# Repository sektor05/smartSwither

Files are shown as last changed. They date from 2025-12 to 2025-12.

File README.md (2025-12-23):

# Smart CAN Bus Switcher

This project is a DIY home automation solution for smart lighting, built around a custom PCB that fits into a standard electrical switch box. It uses a wired CAN bus for robust communication, controlled by a central single-board computer like Orange Pi. This approach provides industrial-grade reliability for your smart home.

## Key Features

*   **Dual Load Control:** Each module has two on-board triacs, allowing it to control two independent lighting groups.
*   **Dimming Functionality:** Supports dimmable LED lamps for smooth brightness adjustments, enabling "sunrise" or "soft evening light" scenes.
*   **Built-in Climate Monitoring:** An integrated temperature sensor in every switch turns your entire home into a climate monitoring network.
*   **Reliable Communication:** Operates over a 2-pair cable, with one pair for 12/24V power and the other for the CAN differential line.

## System Architecture

The heart of the system is a single-board computer (e.g., Orange Pi), which acts as the central brain.

1.  **Central Controller (Orange Pi):**
    *   Collects data from all switches via the CAN bus.
    *   Processes all automation logic (e.g., an "All Off" button at the entrance).
    *   Integrates with external services and voice assistants like Yandex Alice.
2.  **Smart Switch Modules:** Custom PCBs installed in wall switch boxes. They execute commands received from the controller and report status and sensor data.
3.  **CAN Bus:** The backbone of the system, providing a high-speed, reliable, and noise-immune communication link between the controller and all modules.

The server software can be implemented using platforms like **Home Assistant** or custom applications written in **Python/C++**, allowing for easy integration with smart home ecosystems. A command like *"Alice, set the living room light to 30%"* is sent to the Orange Pi, which instantly relays it to the appropriate module on the CAN bus to adjust the light level.

## Why CAN Bus over Zigbee/Wi-Fi?

For a new construction or major renovation, a wired solution offers significant advantages over popular wireless protocols.

| Characteristic | This Solution (CAN Bus) | Popular Wireless (Zigbee) |
| --- | --- | --- |
| **Reliability** | Maximum. Immune to interference from Wi-Fi or microwaves. | Depends on RF signal quality and the number of repeaters. |
| **Speed** | Instantaneous response (milliseconds). | Delays are possible as nodes wake up or the mesh network adjusts. |
| **Power** | Centralized. No batteries to replace in sensors. | Requires battery changes or modules connected to a neutral wire. |
| **Scalability** | Line length can extend to hundreds of meters. | Limited by the radio signal range. |

The main benefit: a wired system is a "set it and forget it" solution. It won't fail because of a router firmware update or a new neighbor's Wi-Fi network.

## Project Structure

*   **/firmware/**: Contains firmware for the microcontroller (STM32/Arduino) on the switch modules. Includes projects for PlatformIO and STM32Cube.
*   **/hardware/**: Datasheets for components used in the project.
*   **/production/**: PCB manufacturing files, including KiCad project, Gerber files, and Bill of Materials (BOM).
*   **/software/**: Server-side applications and scripts for the Orange Pi.
*   **/documents/**: Design documents, manuals, and reports.

## Installation and Wiring

The system uses a 2-pair cable (e.g., KSPV or shielded twisted pair) for both power and data.

*   **Pair 1:** Power (GND / VCC)
*   **Pair 2:** Data (CAN-High / CAN-Low)

The PCB is designed to be compact, leaving enough space for wiring even in shallow switch boxes.

## Related Articles

*   [Умный свет своими руками: Делаем "умным" любой выключатель по шине CAN](https://project-wave.ru/2025/12/23/%d1%83%d0%bc%d0%bd%d1%8b%d0%b9-%d1%81%d0%b2%d0%b5%d0%b4-%d1%81%d0%b2%d0%be%d0%b8%d0%bc%d0%b8-%d1%80%d1%83%d0%ba%d0%b0%d0%bc%d0%b8-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)

The next article will provide a detailed breakdown of the PCB schematic, component selection, and the board layout process in EasyEDA/KiCad.

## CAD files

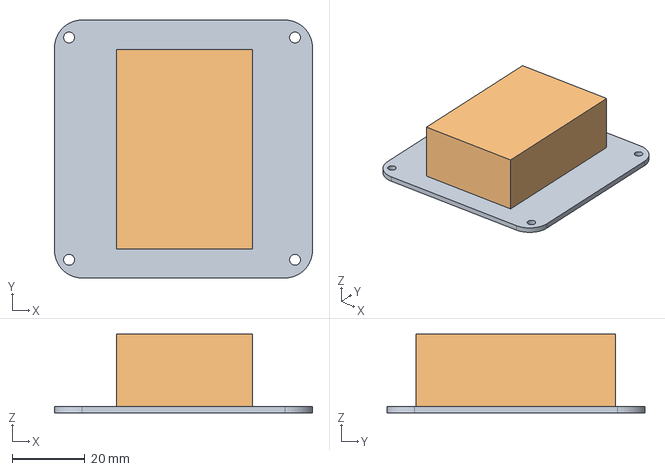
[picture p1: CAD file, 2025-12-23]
production/включаетль.FCStd
70.8 x 70.8 x 21.6 mm
Куб001

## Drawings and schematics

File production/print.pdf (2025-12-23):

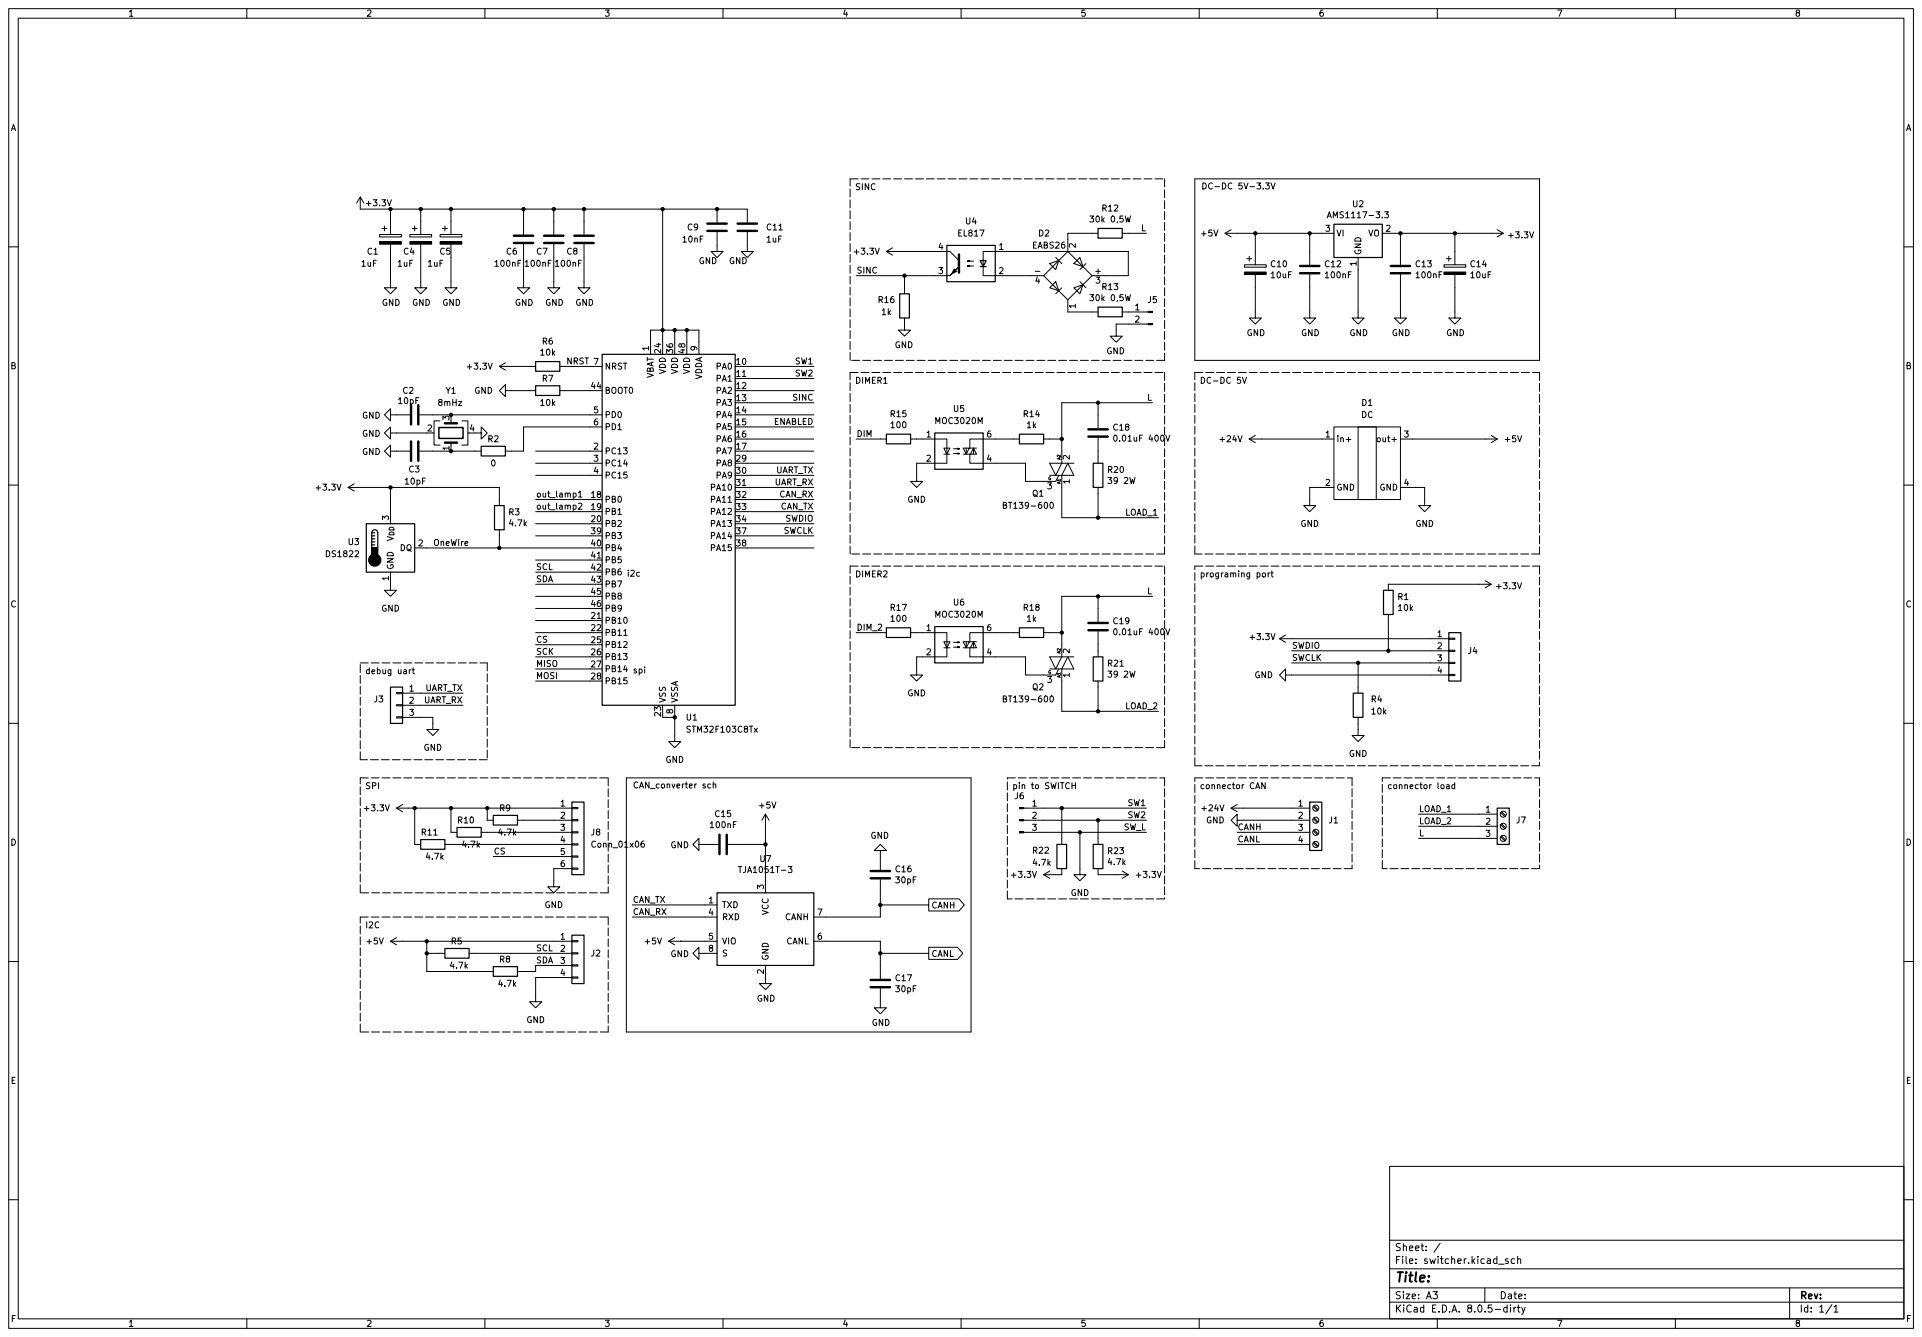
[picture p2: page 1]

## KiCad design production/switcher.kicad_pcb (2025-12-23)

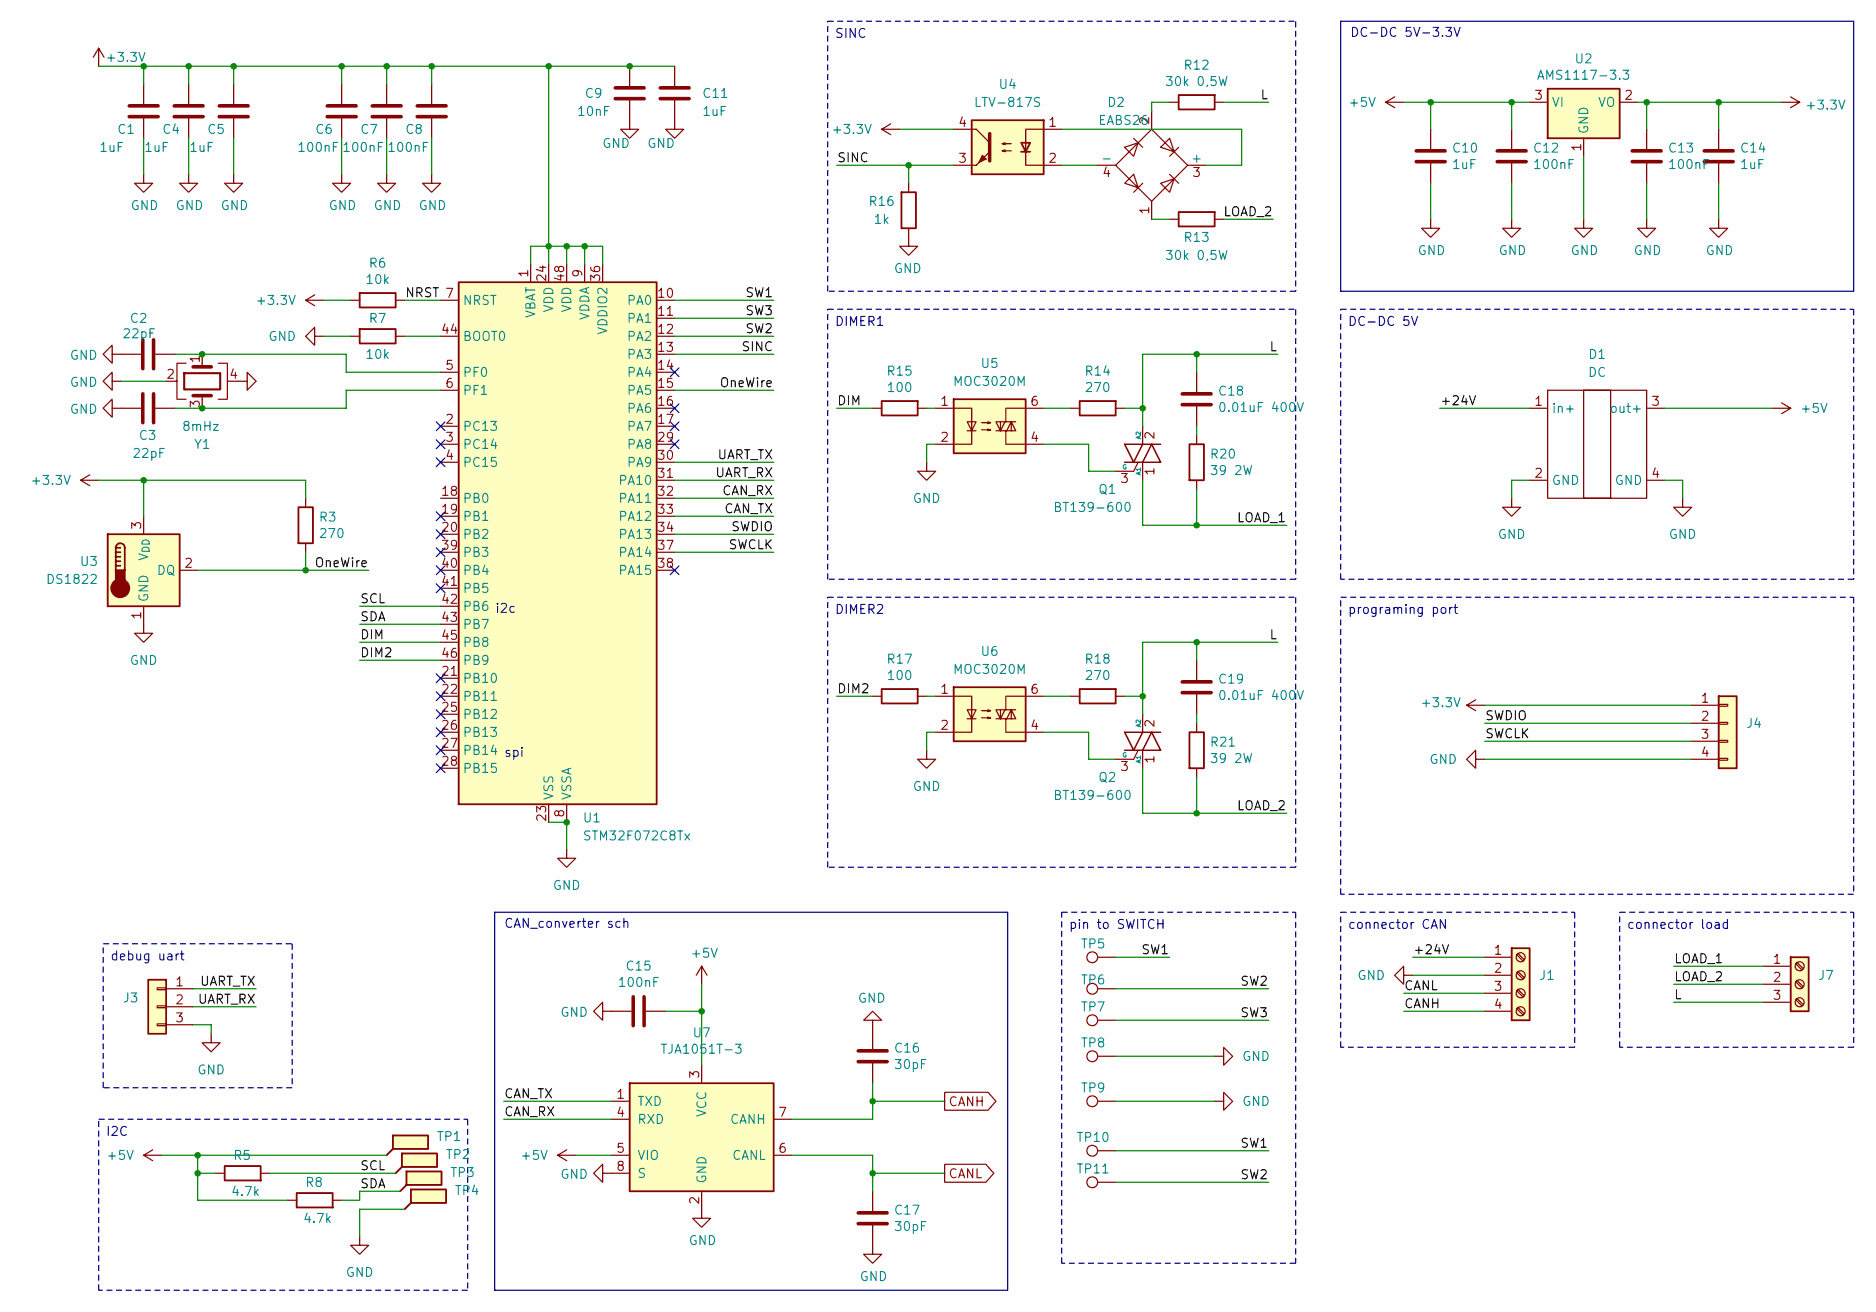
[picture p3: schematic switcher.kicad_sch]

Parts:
C1, C4, C5, C10, C11, C14: 1uF; C_0805_2012Metric
C2, C3: 22pF; C_0805_2012Metric
C6, C7, C8, C12, C13, C15: 100nF; C_0805_2012Metric
C9: 10nF; C_0805_2012Metric
C16, C17: 30pF; C_0805_2012Metric
C18, C19: 0.01uF 400V; C_Rect_L10.0mm_W2.5mm_P7.50mm_MKS4
D1: DC; 30V 3A
D2: EABS26; Diode_Bridge_Diotec_ABS
J1: Screw_Terminal_01x04; KF128-4P
J3: Conn_01x03
J4: Conn_01x04; PinHeader_1x04_P2.54mm_Vertical
J7: Screw_Terminal_01x03; KF128-3P
Q1, Q2: BT139-600; TO-220-3_Vertical
R3: 270; R_0805_2012Metric
R5, R8: 4.7k; R_0805_2012Metric
R6, R7: 10k; R_0805_2012Metric
R12, R13: 30k 0,5W; R_1206_3216Metric
R14, R18: 270; R_1206_3216Metric
R15, R17: 100; R_0805_2012Metric
R16: 1k; R_0805_2012Metric
R20, R21: 39 2W; R_Axial_DIN0414_L11.9mm_D4.5mm_P5.08mm_Vertical
TP1, TP2, TP3, TP4: TestPoint_Flag; TestPoint_Pad_1.0x1.0mm
TP5, TP6, TP7, TP8, TP9, TP10, TP11: TestPoint; TestPoint_Loop_D2.60mm_Drill1.6mm_Beaded
U1: STM32F072C8Tx; LQFP-48_7x7mm_P0.5mm
U2: AMS1117-3.3; SOT-223-3_TabPin2
U3: DS1822; TO-92_Inline
U4: LTV-817S; SMDIP-4_W9.53mm
U5, U6: MOC3020M; DIP-6_W7.62mm
U7: TJA1051T-3; SOIC-8_3.9x4.9mm_P1.27mm
Y1: 8mHz; Crystal_SMD_5032-4Pin_5.0x3.2mm

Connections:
+3.3V: C1.1, C4.1, C5.1, C6.1, C7.1, C8.1, C9.2, C11.1, C13.1, C14.1, J4.1, R3.1, R6.2, U1.1 (VBAT), U1.9 (VDDA), U1.24 (VDD), U1.36 (VDDIO2), U1.48 (VDD), U2.2 (VO), U3.3 (V_{DD}), U4.4
+5V: C10.1, C12.1, C15.1, D1.3 (out+), R5.1, R8.1, TP1.1, U2.3 (VI), U7.3 (VCC), U7.5 (VIO)
/+24V: D1.1 (in+), J1.1
/CAN_RX: U1.32 (PA11), U7.4 (RXD)
/CAN_TX: U1.33 (PA12), U7.1 (TXD)
/DIM: R15.1, U1.45 (PB8)
/DIM2: R17.1, U1.46 (PB9)
/L: C18.1, C19.1, J7.3, Q1.2 (A2), Q2.2 (A2), R12.2, R14.2, R18.2
/LOAD_1: J7.1, Q1.1 (A1), R20.2
/LOAD_2: J7.2, Q2.1 (A1), R13.2, R21.2
/NRST: R6.1, U1.7 (NRST)
/OneWire: R3.2, U1.15 (PA5), U3.2 (DQ)
/SCL: R5.2, TP2.1, U1.42 (PB6)
/SDA: R8.2, TP3.1, U1.43 (PB7)
/SINC: R16.2, U1.13 (PA3), U4.3
/SW1: TP5.1, TP10.1, U1.10 (PA0)
/SW2: TP6.1, TP11.1, U1.12 (PA2)
/SW3: TP7.1, U1.11 (PA1)
/SWCLK: J4.3, U1.37 (PA14)
/SWDIO: J4.2, U1.34 (PA13)
/UART_RX: J3.2, U1.31 (PA10)
/UART_TX: J3.1, U1.30 (PA9)
CANH: C16.2, J1.4, U7.7 (CANH)
CANL: C17.1, J1.3, U7.6 (CANL)
GND: C1.2, C2.1, C3.1, C4.2, C5.2, C6.2, C7.2, C8.2, C9.1, C10.2, C11.2, C12.2, C13.2, C14.2, C15.2, C16.1, C17.2, D1.2 (GND), D1.4 (GND), J1.2, J4.4, R7.2, R16.1, TP4.1, TP8.1, TP9.1, U1.8 (VSSA), U1.23 (VSS), U1.35 (VSS), U1.47 (VSS), U2.1 (GND), U3.1 (GND), U5.2, U6.2, U7.2 (GND), U7.8 (S), Y1.2, Y1.4
unnamed: C18.2, R20.1
unnamed: C19.2, R21.1
unnamed: D2.3 (+), U4.1
unnamed: D2.4 (-), U4.2
unnamed: D2.1, R13.1
unnamed: D2.2, R12.1
unnamed: Q1.3 (G), U5.4
unnamed: Q2.3 (G), U6.4
unnamed: R14.1, U5.6
unnamed: R15.2, U5.1
unnamed: R17.2, U6.1
unnamed: R18.1, U6.6
unnamed: R7.1, U1.44 (BOOT0)
unnamed: C2.2, U1.5 (PF0), Y1.1
unnamed: C3.2, U1.6 (PF1), Y1.3

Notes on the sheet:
spi
DC-DC 5V-3.3V
i2c
CAN_converter sch
DIMER1
programing port
DIMER2
pin to SWITCH
I2C
DC-DC 5V
SINC
connector CAN
connector load
debug uart

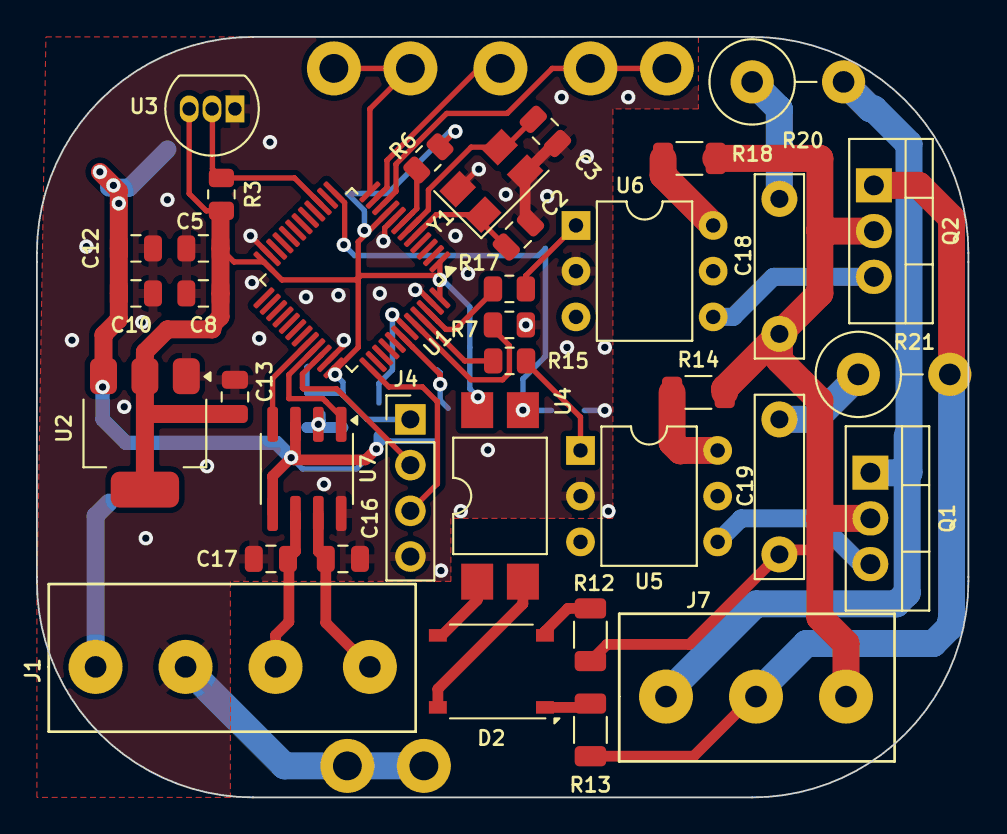
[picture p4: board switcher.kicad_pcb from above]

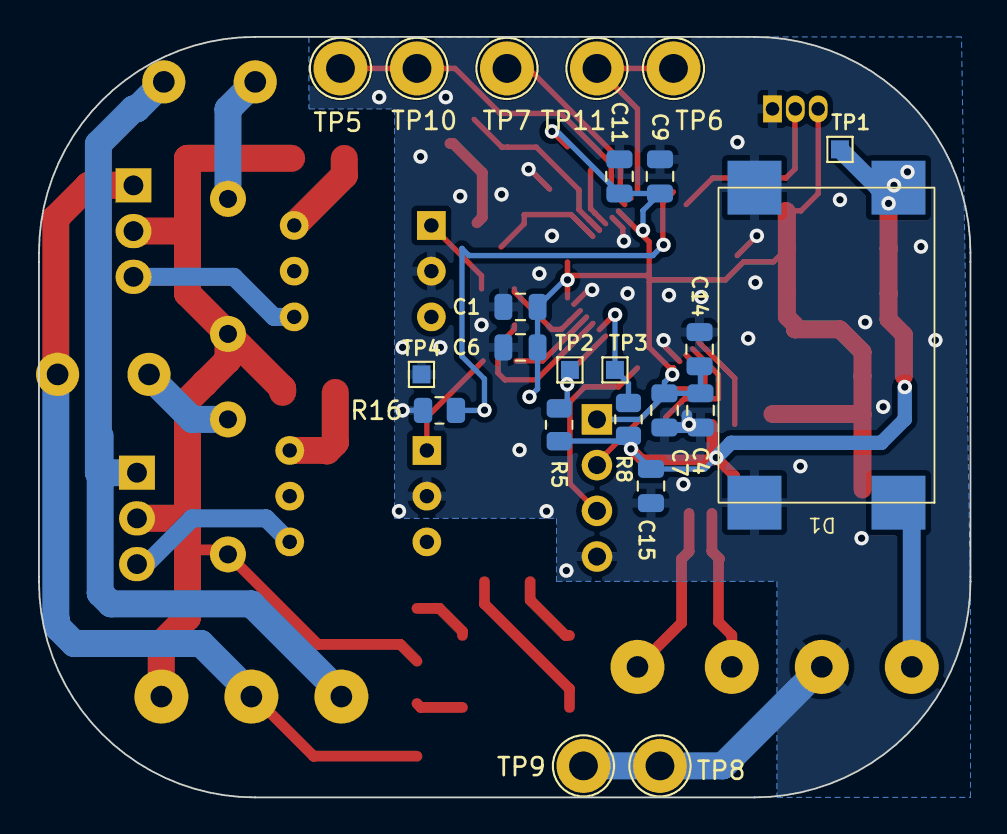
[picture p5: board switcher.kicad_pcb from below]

Board: 2 copper layers, 51.8 x 42.2 mm, 59 parts (23 on the bottom side), 38 nets.

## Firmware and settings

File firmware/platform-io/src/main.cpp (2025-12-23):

/*
 * Основной файл прошивки для умного переключателя на базе STM32F103
 * Реализует управление диммерами, обработку входов, CAN-коммуникацию и измерение температуры
 */

#include <Arduino.h>
#include "myBoard.h"
#include <Wire.h>
#include <cstdint>
#include <eXoCAN.h>
#include <iterator>
#include <stm32f1xx.h>
#include <stm32f1xx_hal.h>
#include <stm32f1xx_ll_gpio.h>
// Явные объявления функций memcpy, memset, memcmp для обхода проблем компиляции

// Создание экземпляра класса платы
myBoard board;

//------------------входные переменные--------------------------------
// Переменные для хранения предыдущих состояний входов
bool prevIn1, prevIn2, prevIn3, prevIn4;
// Переменные для хранения текущих состояний входов
bool in1, in2, in3, in4;

// Объявление аппаратных таймеров для различных задач
HardwareTimer timer(TIM2), timPWM(TIM1), timTemp(TIM3);

// Переменные для CAN-соединения
int id = 0, fltIdx = 0;

// Пины для управления диммерами
const uint16_t dimPins[] = {DIM_PIN, DIM2_PIN};
bool sendFlag = false;
// Буфер для отслеживания изменений в EEPROM (больше не нужен)
// uint8_t flagDataEEPROM[8];
//-----------------------------------------------------
// Буфер для приёма CAN-сообщений
uint8_t rxbytes[8];

int indexAdres = 0;
// Интервал отправки данных о температуре (30 секунд)
#define SEND_TEMP_TIME 30000 // sec

//---------------------------------счётчики------------------------------------------
uint32_t count = 0;
uint16_t tic = 0;

//----------------------------------температура--------------------------------------
#define maxSensors 1
// Массив для хранения значений температуры (в десятых долях градуса)
uint16_t temp[maxSensors];
bool flagD = false;

// Флаги для отслеживания изменений EEPROM (больше не нужны, т.к. запись идет в прерывании)
// bool eepromChanged = false;
// uint32_t lastEepromSave = 0;
// #define EEPROM_SAVE_DELAY 1000 // ms

///////////////////////////////объявления функций///////////////////////////////////////////////
void detect_down();
void detect_up();

/**
 * @brief Чтение температуры с датчика LM335
 * @return Температура в градусах Цельсия
 *
 * Функция считывает аналоговое значение с датчика LM335,
 * преобразует его в напряжение, а затем в температуру по формуле:
 * T(°C) = (V * 100) - 273.15
 */
double readTemperatureLM335() {
   // Считываем сырое значение с АЦП (12-бит, диапазон 0-4095)
   int raw = analogRead(ONE_W);
   // Преобразуем сырое значение в напряжение (опорное 3.3В)
   double voltage = raw * (3.3f / 4095.0f);
   // Преобразуем напряжение в температуру по формуле датчика LM335
   double temperatureC = (voltage * 100) - 273.15f;
   return temperatureC;
}

//------------------------обработчик прерывания CAN-------------------------------------
/**
 * @brief Обработчик прерывания для приёма CAN-сообщений
 *
 * Функция обрабатывает входящие CAN-сообщения различных типов:
 * - EEPROM: сохранение конфигурации
 * - OK: подтверждение получения
 * - PWM1/PWM2: управление ШИМ-каналами
 */
void canRecive() {
    // Проверяем наличие принятых данных
    uint8_t _data[1] = {1};
    if(board.receive(id, fltIdx, rxbytes) > 0) {
       
       // Обработка сообщения для записи в EEPROM
       if(id == (CAN_ID_EEPROM + board.addres)) {
          // Копируем данные в буфер
          memcpy(board.dataEPPROM, rxbytes, sizeof(board.dataEPPROM));
          // Прямая запись в EEPROM из прерывания
          board.saveDataToEPPROM(board.dataEPPROM);
          // Отправляем подтверждение приёма
          board.transmit(CAN_ID_OKtx, _data, sizeof(_data));
          // Перезагрузка микроконтроллера без задержки
          NVIC_SystemReset();
          
       } else if(id == (CAN_ID_OKrx + board.addres)) {
          // Обработка подтверждения получения
          if(_data[0]) board.canResponseFlag = true;
          
       } else if(id == (CAN_ID_PWM1 + board.addres)) {
          // Управление первым ШИМ-каналом
          // rxbytes[0] - целевое значение ШИМ (%)
          // rxbytes[1] - время перехода (мс)
          // rxbytes[2] - начальное значение ШИМ (%)
          board.PWM(0, rxbytes[0], rxbytes[1], rxbytes[2]);
          board.transmit(CAN_ID_OKtx + board.addres, _data, sizeof(_data));
          
       } else if(id == (CAN_ID_PWM2 + board.addres)) {
          // Управление вторым ШИМ-каналом
          board.PWM(1, rxbytes[0], rxbytes[1], rxbytes[2]);
          board.transmit(CAN_ID_OKtx + board.addres, _data, sizeof(_data));
       }
    }
}


//-----------обработчики прерываний по таймеру----------------
/**
 * @brief Обновление значений ШИМ
 *
 * Вызывается по прерыванию таймера для плавного изменения значений ШИМ
 */
void updatePWM() {
   board.updatePWM();
}

/**
 * @brief Отправка данных о температуре по CAN
 *
 * Вызывается по прерыванию таймера с периодом SEND_TEMP_TIME
 */
void sendTempCan() {
   double tempC = readTemperatureLM335();
   // Сохраняем температуру в десятых долях градуса для точности
   temp[0] = static_cast<int16_t>(tempC * 10);
   board.canTX16(CAN_ID_TEMP + board.addres, temp, 1); // 1 датчик, не 2
}

/**
 * @brief Прерывание для управления диммером (без нейтрали)
 *
 * Управляет моментом открытия симистора в зависимости от фазы переменного тока
 */
void isr() {
   tic++;

   for (int i = 0; i < 2; i++) {
      // Проверяем, находится ли значение диммера в допустимом диапазоне
      if ((board.dimmer[i] < MIN_DIM) && (board.dimmer[i] > MAX_DIM)) {
         // В нужный момент времени открываем симистор
         if (tic == board.dimmer[i]) {
            HAL_GPIO_WritePin(GPIOB, dimPins[i], GPIO_PIN_SET);
         } else if (tic >= board.dimmer[i] + 2) {
            // Закрываем симистор через 2 тика после открытия
            HAL_GPIO_WritePin(GPIOB, dimPins[i], GPIO_PIN_RESET);
            // Для второго канала останавливаем таймер
            if (i == 1) timer.pause();
         }
      } else {
         // Если значение вне диапазона, устанавиваем постоянное состояние
         GPIO_PinState st = (board.dimmer[i] == 0) ? GPIO_PIN_SET : GPIO_PIN_RESET;
         HAL_GPIO_WritePin(GPIOB, dimPins[i], st);
      }
   }
}

/**
 * @brief Обработчик перехода через ноль (detect_up)
 *
 * Сбрасывает счётчик и перезапускает таймер при обнаружении перехода через ноль
 */
void detect_up() {
   tic = 0;
   // Сбрасываем оба выхода диммера
   HAL_GPIO_WritePin(GPIOB, dimPins[1], GPIO_PIN_RESET);
   HAL_GPIO_WritePin(GPIOB, dimPins[0], GPIO_PIN_RESET);
   timer.setCount(0);
   timer.refresh();
   timer.resume();
}

/**
 * @brief Прерывание для CAN-шины
 */
void canISR() {
    canRecive();
}

/**
 * @brief Инициализация системы
 *
 * Настраивает все периферийные устройства: CAN, таймеры, прерывания
 */
void setup() {
   // Инициализация платы и CAN-интерфейса
   board.initBoard();
   board.attachInterrupt(canISR);
   
   //-----------------настройка прерываний-----------------------
   // Прерывание по переходу через ноль (детектор синхронизации)
   attachInterrupt(SINC, detect_up, RISING);
   
   // Настройка таймера для плавного изменения ШИМ
   // TODO: Исправить прерывания таймера для совместимости с текущей версией библиотеки
   // timPWM.setMode(1, TIMER_OUTPUT_COMPARE);
   // timPWM.setCompare(1, 0);
   timPWM.attachInterrupt(updatePWM);
   timPWM.setOverflow(MIN_DIM, HERTZ_FORMAT);
   timPWM.resume();

   // Настройка таймера для периодической отправки температуры
   // TODO: Исправить прерывания таймера для совместимости с текущей версией библиотеки
   // timTemp.setMode(1, TIMER_OUTPUT_COMPARE);
   // timTemp.setCompare(1, 0);
   timTemp.attachInterrupt(sendTempCan);
   timTemp.setOverflow(SEND_TEMP_TIME*1000, MICROSEC_FORMAT);
   timTemp.resume();
   
   // Настройка таймера для управления диммером (40 мкс период)
   // TODO: Исправить прерывания таймера для совместимости с текущей версией библиотеки
   // timer.setMode(1, TIMER_OUTPUT_COMPARE);
   // timer.setCompare(1, 0);
   timer.attachInterrupt(isr);
   timer.setOverflow(40, MICROSEC_FORMAT);
   
   // Инициализация значений диммеров (выключены)
   board.dimmer[0] = 255;
   board.dimmer[1] = 255;

   // Первоначальная отправка температуры при старте
   double tempC = readTemperatureLM335();
   temp[0] = static_cast<int16_t>(tempC * 10);
   board.canTX16(CAN_ID_TEMP + board.addres, temp, 1);
   
   // Буфер flagDataEEPROM больше не нужен, т.к. запись в EEPROM происходит в прерывании
}

uint32_t last = 0;

/**
 * @brief Основной цикл программы
 *
 * Обрабатывает входы, управляет ШИМ, обрабатывает CAN-сообщения
 * и сохраняет изменения в EEPROM при необходимости
 */
void loop() {
   //------------чтение и отправка состояний входов----------------------------
   board.controlIn();  // Считываем состояния входов
   board.processCan(); // Обрабатываем очередь CAN-сообщений
   // Отправляем состояния входов по CAN
   board.canTX(CAN_ID_IN + board.addres, board.in, sizeof(board.in));
   
   // Управление ШИМ на основе состояний входов (локальный режим)
   if(!board.serverAvail) {
      // Если хотя бы один вход активен (низкий уровень), включаем ШИМ
      if(!board.in[0] || !board.in[1] || !board.in[2]) {
         board.PWM(0, 100, 0, 0); // Включаем первый канал на 100%
         board.PWM(1, 100, 0, 0); // Включаем второй канал на 100%
      } else {
         board.PWM(0, 0, 0, 0);   // Выключаем первый канал
         board.PWM(1, 0, 0, 0);   // Выключаем второй канал
      }
   }

   // Сохранение в EEPROM теперь происходит напрямую в прерывании canRecive()
   // Этот код больше не нужен
   
   delay(10); // Небольшая задержка для стабильности работы
}

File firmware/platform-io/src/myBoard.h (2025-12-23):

/*
 * Заголовочный файл класса myBoard
 * Определяет функционал для управления платой умного переключателя
 * Включает управление диммерами, CAN-коммуникацию, работу с EEPROM
 */

#ifndef MY_BOARD_H
#define MY_BOARD_H

/*
 * Заголовочный файл класса myBoard
 * Определяет функционал для управления платой умного переключателя:
 * - Управление диммерами и ШИМ
 * - CAN-коммуникация
 * - Работа с EEPROM
 * - Обработка входов
 */

#include <Arduino.h>
#include "EEPROM.h"
#include <eXoCAN.h>
#include <stm32f1xx.h>
#include <cstring>
#include <stm32f1xx_hal.h>

// Явные объявления функций memcpy, memset, memcmp для обхода проблем компиляции
extern "C" {
void *memcpy(void *dest, const void *src, size_t n);
void *memset(void *s, int c, size_t n);
int memcmp(const void *s1, const void *s2, size_t n);
}
//------------------определения пинов-------------------

// Пины управления диммерами
#define DIM_PIN PB8
#define DIM2_PIN PB9

// Входные пины
#define IN_1 PA0
#define IN_2 PA1
#define IN_3 PA2

// Пин детектора перехода через ноль (синхронизация)
#define SINC PA3

// CAN-шина пины
#define CAN_RX PA11
#define CAN_TX PA12

// I2C пины
#define I2C_SCL PB6
#define I2C_SDA PB7

// Пины для датчиков
#define ONE_W PA5
#define TEMP_SENSOR_PIN PA5  // Пин, к которому подключён LM335Z

// Адрес в EEPROM для хранения конфигурации
#define CONFIG_ADDR 10

// Пределы диммера (значения для таймера)
#define MIN_DIM 200  // Минимальное значение (максимальная яркость)
#define MAX_DIM 0    // Максимальное значение (минимальная яркость)

//------------------параметры CAN-сообщений (приём)-----------------------
#define CAN_ID_GLOBAL 800  // Глобальный CAN ID
#define CAN_ID_PWM1 801    // Управление первым ШИМ-каналом
#define CAN_ID_PWM2 802    // Управление вторым ШИМ-каналом
#define CAN_ID_EEPROM 803  // Запись в EEPROM
#define CAN_ID_OKrx 804    // Подтверждение приёма

//-------параметры CAN-сообщений (передача)---------------------
#define CAN_ID_IN 806      // Состояния входов
#define CAN_ID_TEMP  807   // Датчик температуры
#define CAN_ID_OKtx 808    // Подтверждение передачи

//----------------индексы данных в EEPROM-----------------
#define CONFIG 0          // Конфигурация устройства


//---------------типы конфигурации устройства-----------------------
#define COSTOM 0          // Пользовательский режим
#define POWER 1           // Режим управления питанием
#define RESTROOM 2        // Режим для ванной комнаты
#define KICHEN 3          // Режим для кухни


/**
 * @brief Класс управления платой умного переключателя
 *
 * Наследуется от eXoCAN для обеспечения CAN-коммуникации.
 * Реализует управление диммерами, ШИМ, обработку входов и работу с EEPROM.
 */
class myBoard: public eXoCAN {
    public:
        // Публичные переменные
        uint8_t config=0;              // Тип конфигурации устройства
        uint8_t addres=0;              // Адрес устройства в CAN-сети
        uint8_t led2=0, led3=0, led4=0; // Состояния светодиодов
        
        uint8_t in[4];                 // Состояния входов
        uint8_t dataEPPROM[8];         // Данные из EEPROM
        uint8_t pwm_balast=0;          // Значение ШИМ балласта для первой лампы, когда включена вторая лампа. Необходима для детектора нуля.
        bool serverAvail = true;       // Флаг доступности сервера CAN

        // Публичные методы
        void initBoard();              // Инициализация платы
        bool contrCheng(int &previousData, int data); // Проверка изменения данных
       
        bool controlIn();              // Контроль входов
        uint8_t IN1();                 // Чтение состояния входа 1
        uint8_t IN2();                 // Чтение состояния входа 2
        uint8_t IN3();                 // Чтение состояния входа 3
        uint8_t dimmer[2];             // Значения диммеров
       
        
        uint8_t PWM(uint8_t chinal, uint8_t pwm, uint16_t time, uint8_t startPercent); // Управление ШИМ с плавным изменением
     
        void exponentialPWM(uint8_t pin, uint16_t duration); // Экспоненциальное изменение ШИМ
        void PWM(uint8_t pin, uint8_t percent);               // Простое управление ШИМ

        // CAN-методы
        bool canTX(int txId, uint8_t *ptr, uint8_t len, bool waitAck = true); // Отправка CAN-сообщения с ожиданием подтверждения
        bool canTX16(int txId, uint16_t *ptr, uint8_t len);                    // Отправка 16-битных данных по CAN
        bool canTX16_notAks(int txId, uint16_t *ptr, uint8_t len);            // Отправка 16-битных данных без подтверждения
        bool canTX_notCont(int txId, const void *ptr, uint8_t len);           // Отправка без непрерывного подтверждения
        void processCan(); // Обработка очереди CAN-сообщений (неблокирующая)
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

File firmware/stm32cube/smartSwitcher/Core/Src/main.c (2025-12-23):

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
/* Includes ------------------------------------------------------------------*/
#include "main.h"
#include "adc.h"
#include "can.h"
#include "dma.h"
#include "tim.h"
#include "gpio.h"

/* USER CODE BEGIN Includes */
#include "stm32f1xx_hal.h"
#include "stm32f1xx_ll_adc.h"
#include "flash_storage.h"
#include "string.h"
/* USER CODE END Includes */


/* USER CODE BEGIN PV */

uint16_t tic = 0;
const uint16_t dimPins[] = {DIM1_Pin, DIM2_Pin};
board_t Brd;
telemetry_t BrdTel;
dimmer_t dm[2] = {
    {MAX_DIM, 10, 10,MIN_DIM, MAX_DIM}, // Диммер 1
    {MAX_DIM, 10, 10,MIN_DIM, MAX_DIM}  // Диммер 2
};
/* USER CODE END PV */

void SystemClock_Config(void);
/* USER CODE BEGIN PFP */

//-------------прерывания по изменения яркости -----------------------
void LightControlDM1() {
    if (dm[CH_DIM_1].dimmer < MIN_DIM) {
        dm[CH_DIM_1].dimmer ++;
        if (dm[CH_DIM_1].dimmer >= MIN_DIM) {
            dm[CH_DIM_1].dimmer = MIN_DIM;
            HAL_TIM_Base_Stop_IT(&htim2);
        }
    } else if (dm[CH_DIM_1].dimmer > MAX_DIM) {
        dm[CH_DIM_1].dimmer --;
        if (dm[CH_DIM_1].dimmer <= MAX_DIM) {
            dm[CH_DIM_1].dimmer = MAX_DIM;
            HAL_TIM_Base_Stop_IT(&htim2);
        }
    }
}

void LightControlDM2() {
    if (dm[CH_DIM_2].dimmer < MIN_DIM) {
        dm[CH_DIM_2].dimmer ++;
        if (dm[CH_DIM_2].dimmer >= MIN_DIM) {
            dm[CH_DIM_2].dimmer = MIN_DIM;
            HAL_TIM_Base_Stop_IT(&htim3);
        }
    } else if (dm[CH_DIM_2].dimmer > MAX_DIM) {
        dm[CH_DIM_2].dimmer --;
        if (dm[CH_DIM_2].dimmer <= MAX_DIM) {
            dm[CH_DIM_2].dimmer = MAX_DIM;
            HAL_TIM_Base_Stop_IT(&htim3);
        }
    }
}

//-------------прерывания по кнопкам----------------
void INT_SW1(){
    BrdTel.sw1 = HAL_GPIO_ReadPin(SW1_GPIO_Port, SW1_Pin);  
}
void INT_SW2(){
    BrdTel.sw2 = HAL_GPIO_ReadPin(SW2_GPIO_Port, SW2_Pin);  
}
void INT_SW3(){
    BrdTel.sw3 = HAL_GPIO_ReadPin(SW3_GPIO_Port, SW3_Pin);  
}


//------------отправка температуры по CAN--------
void sendTempToCAN(){
  BrdTel.temp = (int16_t)(readTemperatureLM335(Adc.FadcChanal) * 10);
  uint8_t tempData[2];
  tempData[0] = (uint8_t)(BrdTel.temp & 0xFF); // Младший байт
  tempData[1] = (uint8_t)(BrdTel.temp >> 8); // Старший байт
 
  AddMessageToQueue(Sh_Id(CAN_ID_TEMP), tempData, 2, SEND_ONLY);
}
/* USER CODE END PFP */

/**
  * @brief  The application entry point.
  * @retval int
  */
int main(void)
{

  /* MCU Configuration--------------------------------------------------------*/

  /* Reset of all peripherals, Initializes the Flash interface and the Systick. */
  HAL_Init();

  /* Configure the system clock */
  SystemClock_Config();

  /* Initialize all configured peripherals */
  MX_GPIO_Init();
  MX_DMA_Init();
  MX_CAN_Init();
  MX_TIM2_Init();
  MX_ADC1_Init();
  MX_TIM1_Init();
  MX_TIM3_Init();
  MX_TIM4_Init();
  /* USER CODE BEGIN 2 */
  HAL_ADC_Start_DMA(&hadc1, (uint32_t*)Adc.adcChanal, CHANALS_ADC);
  HAL_CAN_Start(&hcan);
  HAL_TIM_IC_Start_IT(&htim2, TIM_CHANNEL_4);
  HAL_TIM_Base_Start_IT(&htim1); // таймер на детектора нуля
  HAL_TIM_Base_Start_IT(&htim4); // таймер на 30 сек для отправки температуры

  //----Считываем с флеш памяти адрес платы если там нет значение или = 255 то адресс 0
  Flash_ReadData(&Brd, sizeof(Brd));
  if (Brd.Adres == 0xFF) {
      Brd.Adres = 0;
      Flash_WriteData(&Brd, sizeof(Brd));
  }
  /* USER CODE END 2 */

  /* Infinite loop */
  /* USER CODE BEGIN WHILE */
  while (1)
  {
     ProcessCANQueue();
    /* USER CODE END WHILE */

    /* USER CODE BEGIN 3 */
  }
  /* USER CODE END 3 */
}

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
/* USER CODE BEGIN 4 */
void lightEn(uint8_t ch, uint8_t en) {
  
   if (en == 0) { // выключить
      dm[ch].dimmer = MAX_DIM;
   } else if (en == 1) { // включить
      dm[ch].dimmer = MIN_DIM;
   } else if (en == 2) { // плавное увеличение
      //-------включение таймера для плавного увеличения
      if(ch == CH_DIM_1) {
         SetTimeTimer_Dim1(dm[ch].timeOn);
         HAL_TIM_Base_Start_IT(&htim2);
      }
      if(ch == CH_DIM_2){
         SetTimeTimer_Dim2(dm[ch].timeOn);
         HAL_TIM_Base_Start_IT(&htim3);
      } 
     
   } else if (en == 3) { // плавное уменьшение
      //-------включение таймера для плавного уменьшения
     if(ch == CH_DIM_1) {
         SetTimeTimer_Dim1(dm[ch].timeOff);
         HAL_TIM_Base_Start_IT(&htim2);
      }
      if(ch == CH_DIM_2){
         SetTimeTimer_Dim2(dm[ch].timeOff);
         HAL_TIM_Base_Start_IT(&htim3);
      } 
   }
}

void lightSet(uint8_t ch, uint8_t value, uint8_t time, uint8_t startValue){
   if (value < MIN_DIM) value = MIN_DIM;
   if (value > MAX_DIM) value = MAX_DIM;
   dm[ch].dimmer = value;
   dm[ch].timeOn = time;
   dm[ch].startValue = startValue;
}

long map(long x, long in_min, long in_max, long out_min, long out_max)
{
  return (x - in_min) * (out_max - out_min) / (in_max - in_min) + out_min;
}

/* USER CODE END 4 */
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


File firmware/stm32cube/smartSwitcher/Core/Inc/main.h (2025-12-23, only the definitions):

#define SW1_Pin GPIO_PIN_0
#define SW1_GPIO_Port GPIOA
#define SW3_Pin GPIO_PIN_1
#define SW3_GPIO_Port GPIOA
#define SW2_Pin GPIO_PIN_2
#define SW2_GPIO_Port GPIOA
#define SINC_Pin GPIO_PIN_3
#define SINC_GPIO_Port GPIOA
#define TEMP_Pin GPIO_PIN_5
#define TEMP_GPIO_Port GPIOA
#define DIM1_Pin GPIO_PIN_8
#define DIM1_GPIO_Port GPIOB
#define DIM2_Pin GPIO_PIN_9
#define DIM2_GPIO_Port GPIOB
#define MAX_DIM 0
#define MIN_DIM 200
#define CH_DIM_1 0
#define CH_DIM_2 1

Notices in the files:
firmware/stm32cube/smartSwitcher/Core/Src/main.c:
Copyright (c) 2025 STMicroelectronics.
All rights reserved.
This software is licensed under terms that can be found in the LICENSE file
